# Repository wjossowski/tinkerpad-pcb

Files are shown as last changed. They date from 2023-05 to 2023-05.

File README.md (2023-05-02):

# tinkerpad

Programmable 4x4 Macropad with KMK

### Libraries:

- [GitHub - ebastler/marbastlib: A library collecting MX and Choc style footprints, as well as various other parts used to design custom keyboards](https://github.com/ebastler/marbastlib)

- [GitHub - foostan/kbd: for building keyboard libraries](https://github.com/foostan/kbd)

- [GitHub - ncarandini/KiCad-RP-Pico: A simple repository of files needed to add a 3D footprint of the Raspberry Pi Pico board to KiCad.](https://github.com/ncarandini/KiCad-RP-Pico)

### Todo (V3):

- [ ] RGB diode per key
- [ ] Serial interface plugins (UART, SPI)

### V2:

- [x] Chiral (flippable) board
- [x] Columnar stagger

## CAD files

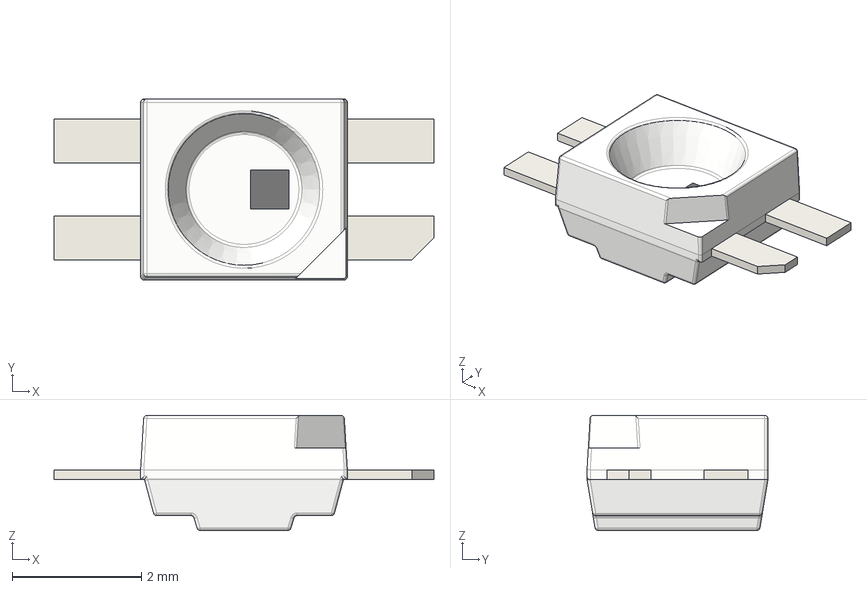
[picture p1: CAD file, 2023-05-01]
3dmodel/LED_SK6812MINI-E.step
5.88 x 2.80 x 1.78 mm

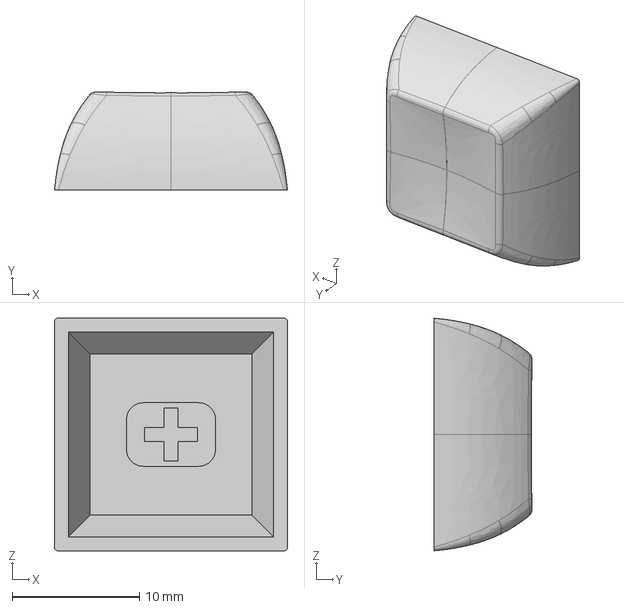
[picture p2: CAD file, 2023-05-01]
3dmodel/DSA_Keycap_CherryMX.step
18.3 x 7.69 x 18.3 mm

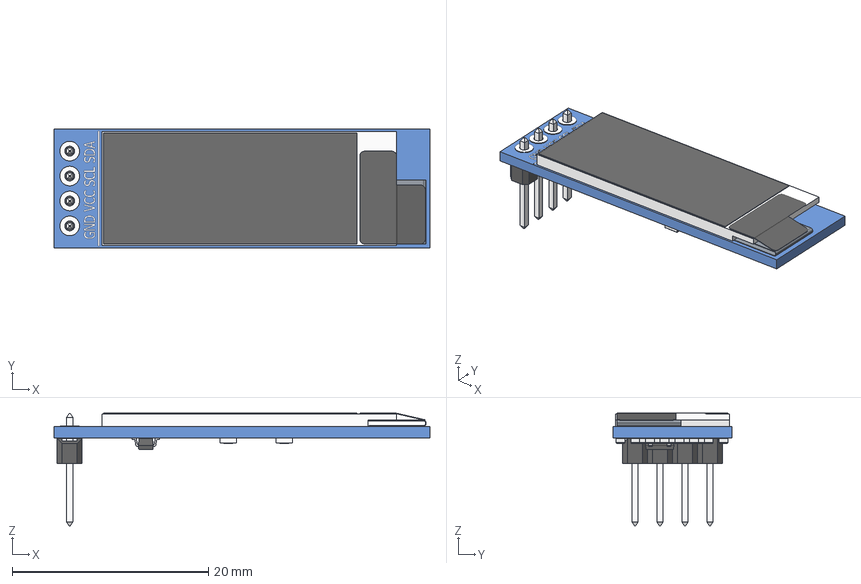
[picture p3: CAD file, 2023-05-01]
3dmodel/OLED_0.91_128x32.stp
38.3 x 12.1 x 11.5 mm
OLED_0.91_128x32
Pin Header 4 x 1 TH 2.54mm Pitch
RESC-0603 x 13
2SD0601A

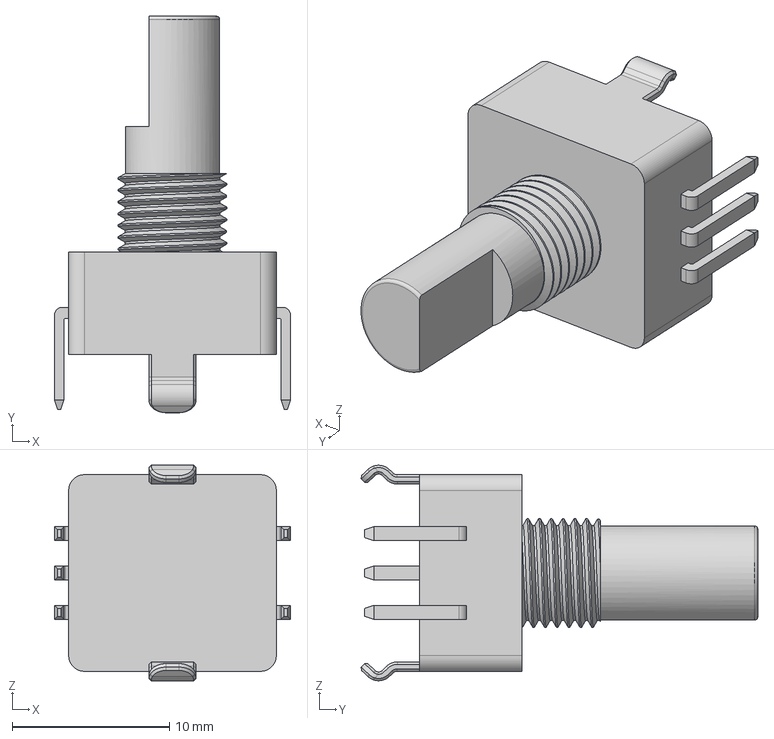
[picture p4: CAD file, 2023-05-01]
3dmodel/Rotary Encoder.step
15.0 x 25.2 x 13.7 mm

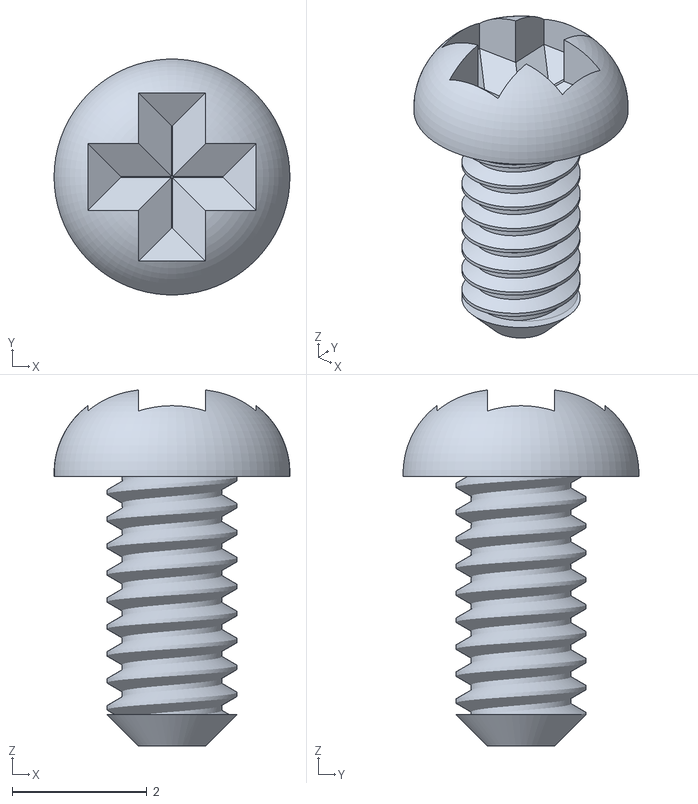
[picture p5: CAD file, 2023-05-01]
3dmodel/m2_screws/M2x4 v1.stl
3.50 x 3.50 x 5.28

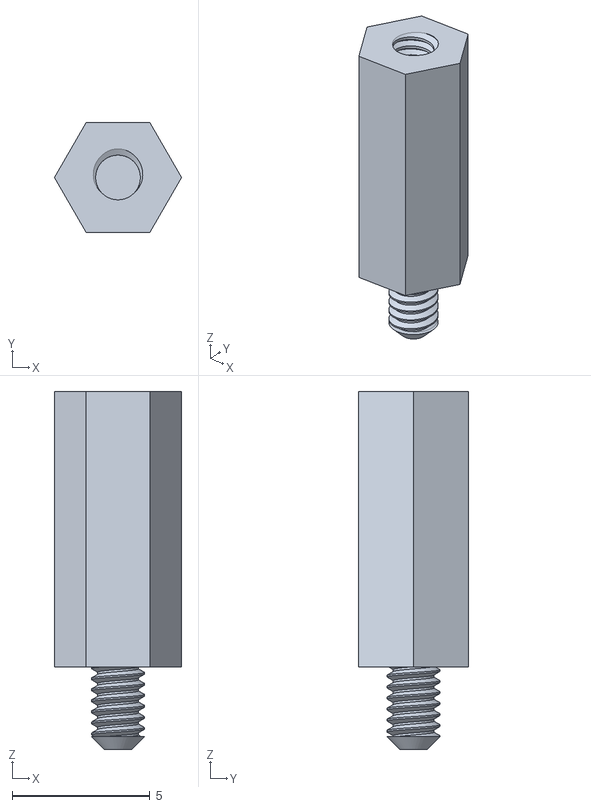
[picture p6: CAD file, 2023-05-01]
3dmodel/m2_screws/M2_10+3 v1.stl
4.62 x 4.00 x 13.0

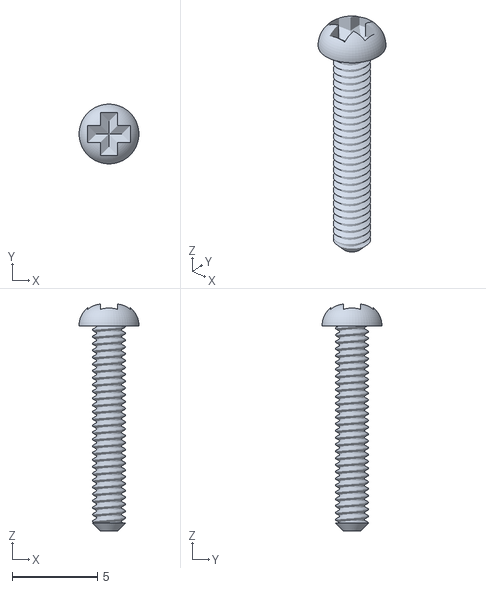
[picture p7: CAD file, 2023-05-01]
3dmodel/m2_screws/M2x12 v1.stl
3.50 x 3.50 x 13.3

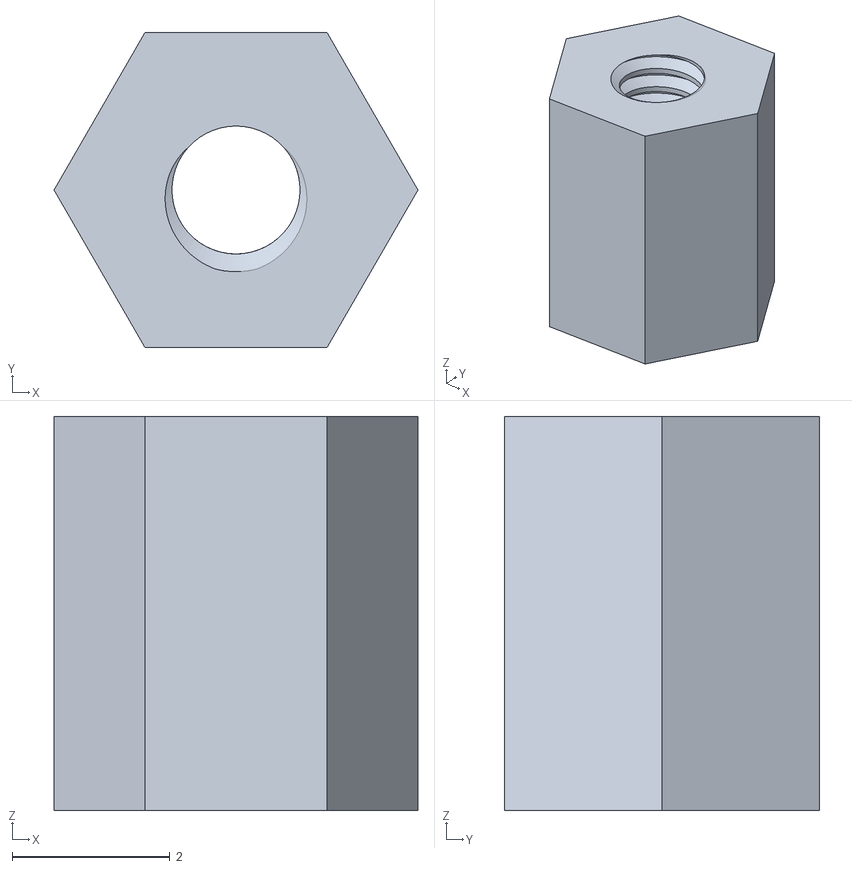
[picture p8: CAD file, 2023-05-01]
3dmodel/m2_screws/M2Sx5 v1.stl
4.62 x 4.00 x 5.00

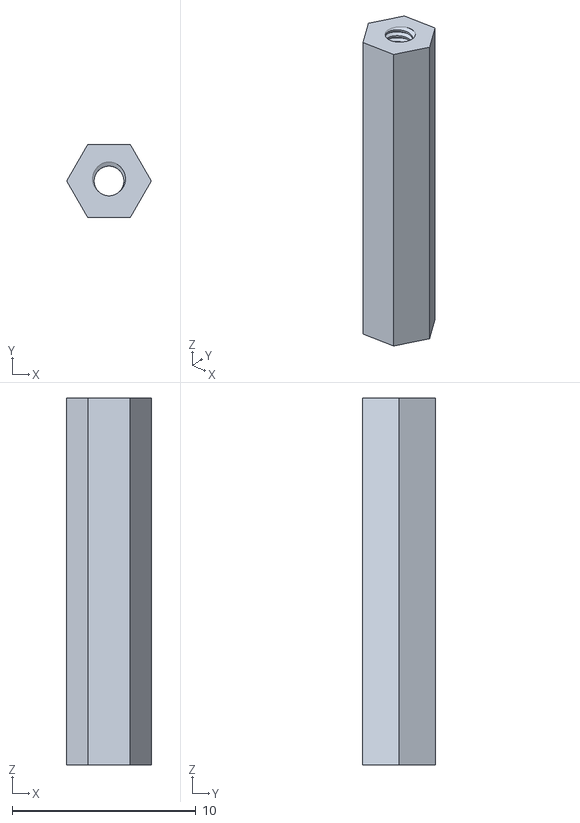
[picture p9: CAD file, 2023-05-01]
3dmodel/m2_screws/M2Sx20 v1.stl
4.62 x 4.00 x 20.0

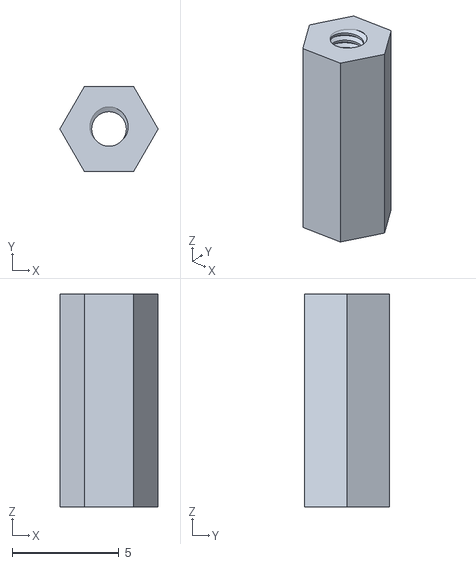
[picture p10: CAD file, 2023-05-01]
3dmodel/m2_screws/M2Sx10 v1.stl
4.62 x 4.00 x 10.0

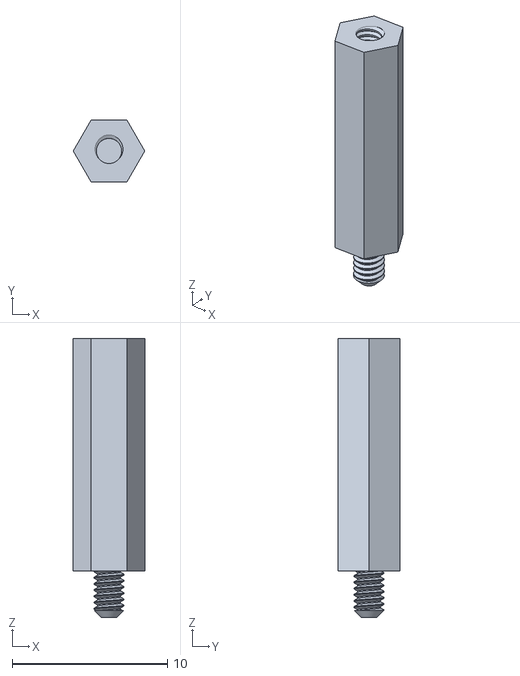
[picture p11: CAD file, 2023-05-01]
3dmodel/m2_screws/M2_15+3 v1.stl
4.62 x 4.00 x 18.0

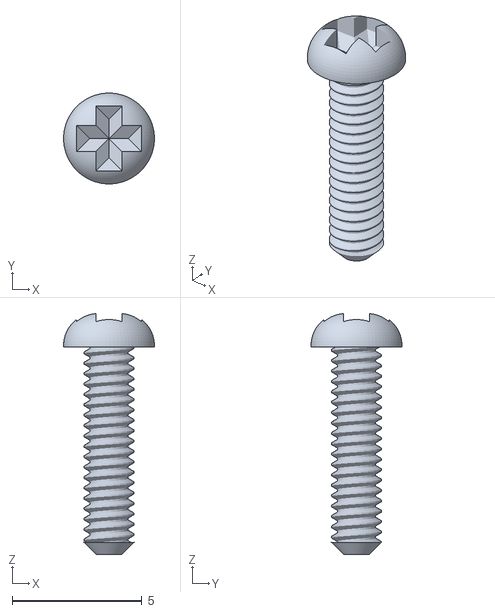
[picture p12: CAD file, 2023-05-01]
3dmodel/m2_screws/M2x8 v1.stl
3.50 x 3.50 x 9.28

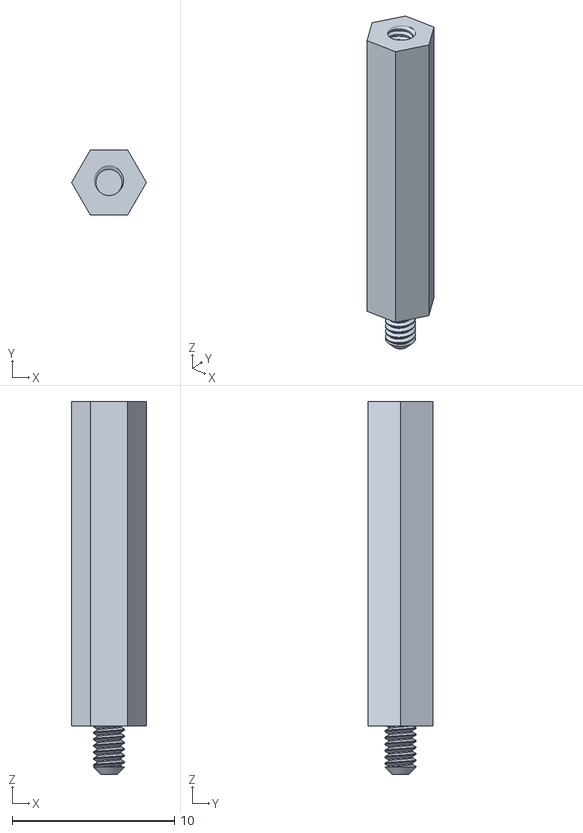
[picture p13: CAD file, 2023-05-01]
3dmodel/m2_screws/M2_20+3 v1.stl
4.62 x 4.00 x 23.0

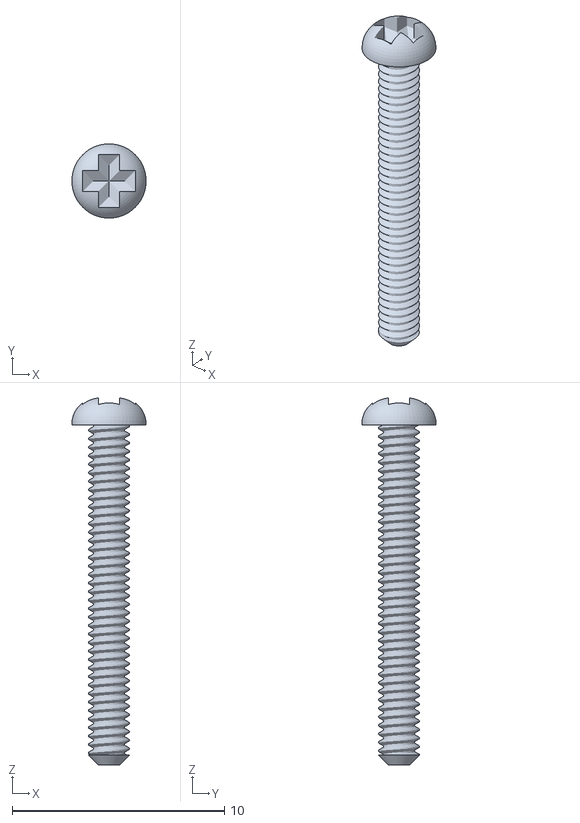
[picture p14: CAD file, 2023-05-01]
3dmodel/m2_screws/M2x16 v1.stl
3.50 x 3.50 x 17.3

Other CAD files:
3dmodel/m2_screws/m2_nut v1.stl
3dmodel/m2_screws/M2x6 v1.stl
3dmodel/m2_screws/M2x10 v1.stl
3dmodel/m2_screws/M2Sx15 v1.stl
3dmodel/m2_screws/M2_5+3 v1.stl

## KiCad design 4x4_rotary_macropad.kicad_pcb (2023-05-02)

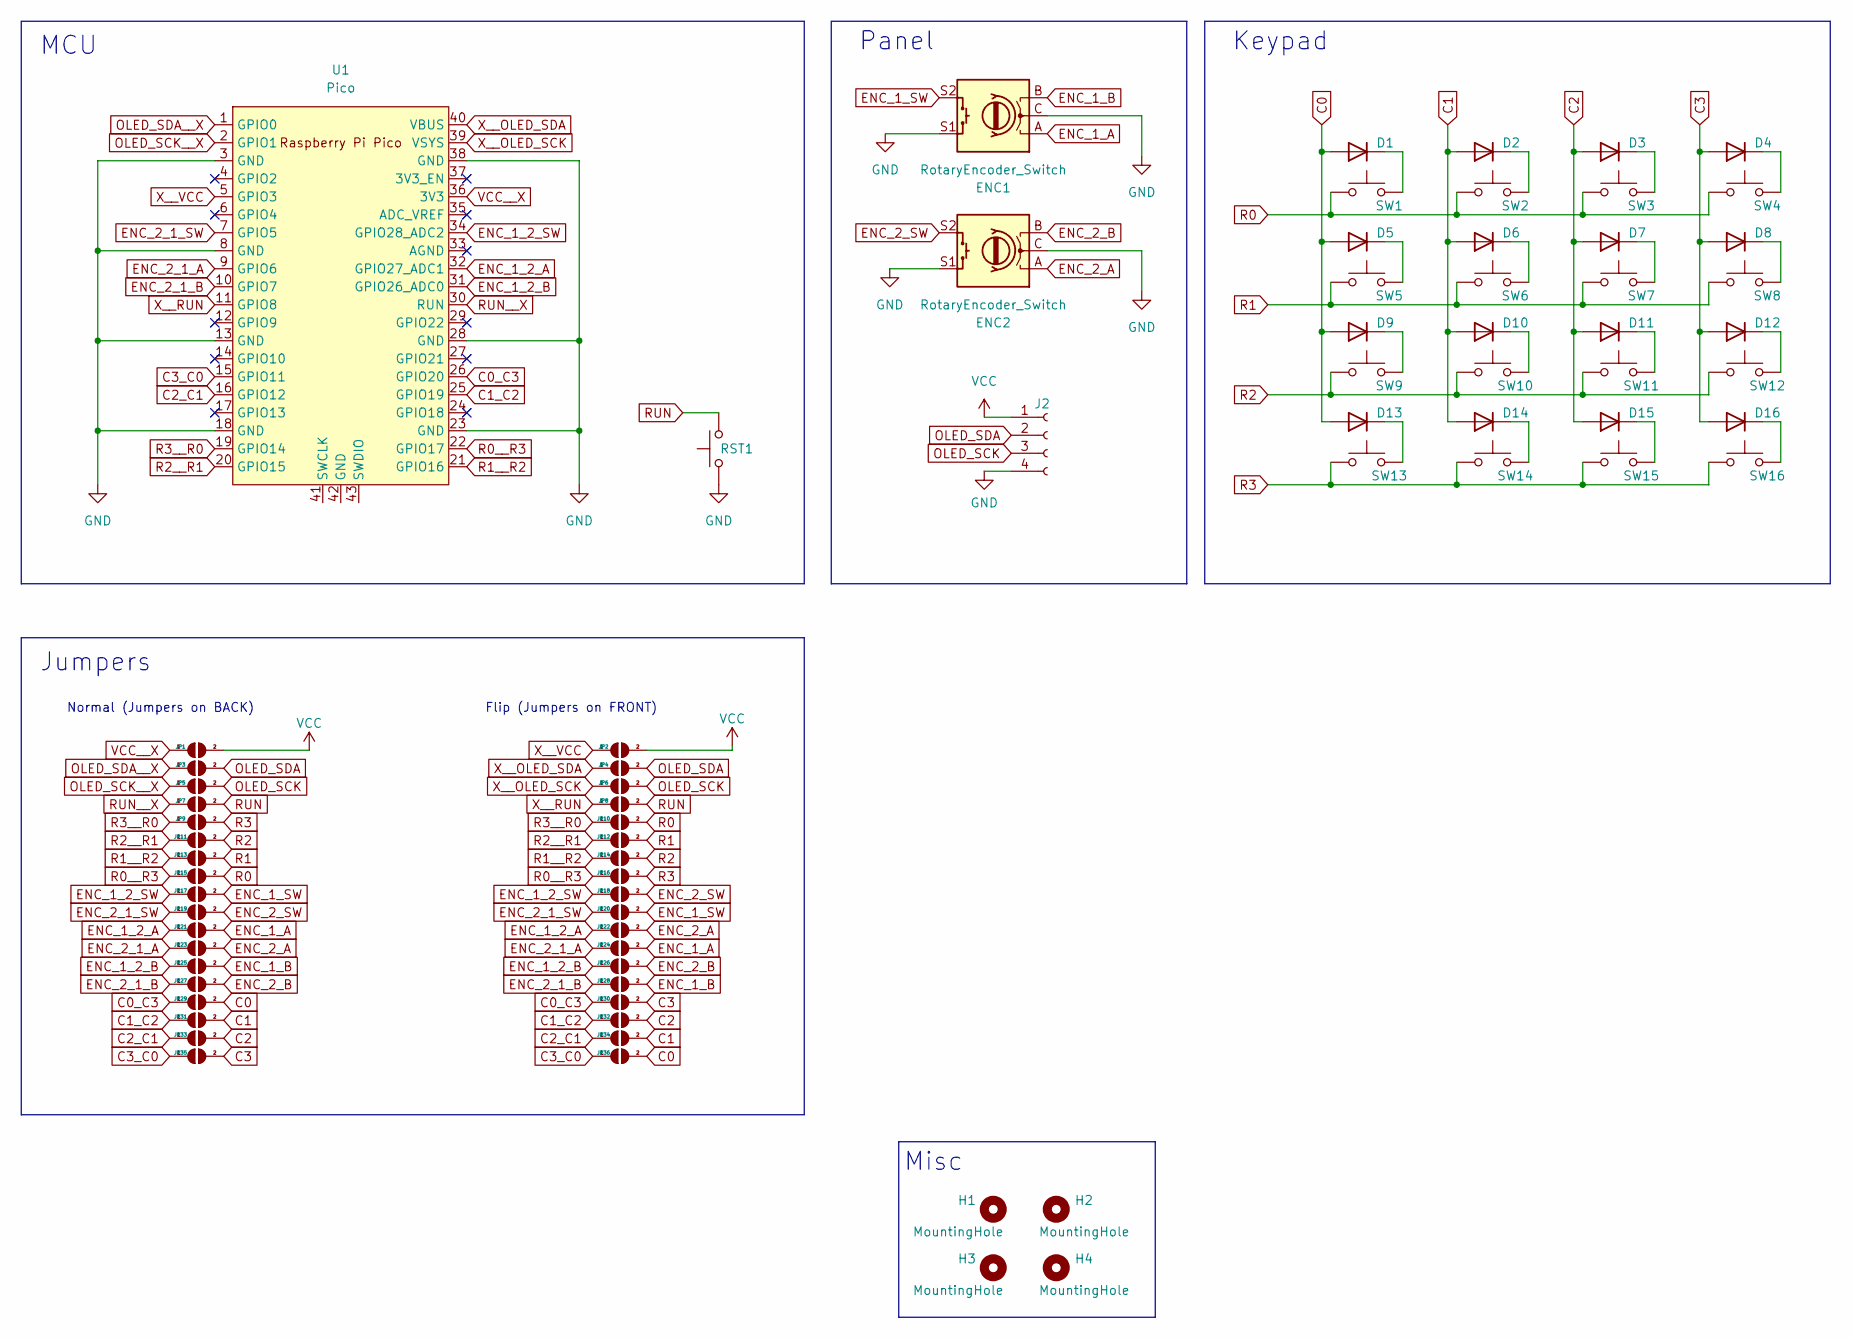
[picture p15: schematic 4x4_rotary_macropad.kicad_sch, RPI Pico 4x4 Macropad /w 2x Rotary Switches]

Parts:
D1, D2, D3, D4, D5, D6, D7, D8, D9, D10, D11, D12, D13, D14, D15, D16: e; D3_TH_SMD_v2
ENC1, ENC2: RotaryEncoder_Switch; RotaryEncoder_Alps_EC12E-Switch_Vertical_H20mm
H1, H2, H3, H4: MountingHole; MountingHole_2.2mm_M2
J2: Conn_01x04_Socket; Hirose_DF13-04P-1.25DSA_1x04_P1.25mm_Vertical
JP1, JP2, JP3, JP4, JP5, JP6, JP7, JP8, JP9, JP10, JP11, JP12, JP13, JP14, JP15, JP16, JP17, JP18, JP19, JP20, JP21, JP22, JP23, JP24, JP25, JP26, JP27, JP28, JP29, JP30, JP31, JP32, JP33, JP34, JP35, JP36: SolderJumper_2_Open; jumper
RST1: SW_Push; SW_SKHLLCA010
SW1, SW2, SW3, SW4, SW5, SW6, SW7, SW8, SW9, SW10, SW11, SW12, SW13, SW14, SW15, SW16: SW_Push; SW_Cherry_MX_PCB_1.00u
U1: Pico; RPi_Pico_SMD_TH

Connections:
C0: D1.2 (A), D5.2 (A), D9.2 (A), D13.2 (A), JP29.2 (B), JP36.2 (B)
C0_C3: JP29.1 (A), JP30.1 (A), U1.26 (GPIO20)
C1: D2.2 (A), D6.2 (A), D10.2 (A), D14.2 (A), JP31.2 (B), JP34.2 (B)
C1_C2: JP31.1 (A), JP32.1 (A), U1.25 (GPIO19)
C2: D3.2 (A), D7.2 (A), D11.2 (A), D15.2 (A), JP32.2 (B), JP33.2 (B)
C2_C1: JP33.1 (A), JP34.1 (A), U1.16 (GPIO12)
C3: D4.2 (A), D8.2 (A), D12.2 (A), D16.2 (A), JP30.2 (B), JP35.2 (B)
C3_C0: JP35.1 (A), JP36.1 (A), U1.15 (GPIO11)
ENC_1_2_A: JP21.1 (A), JP22.1 (A), U1.32 (GPIO27_ADC1)
ENC_1_2_B: JP25.1 (A), JP26.1 (A), U1.31 (GPIO26_ADC0)
ENC_1_2_SW: JP17.1 (A), JP18.1 (A), U1.34 (GPIO28_ADC2)
ENC_1_A: ENC1.A, JP21.2 (B), JP24.2 (B)
ENC_1_B: ENC1.B, JP25.2 (B), JP28.2 (B)
ENC_1_SW: ENC1.S2, JP17.2 (B), JP20.2 (B)
ENC_2_1_A: JP23.1 (A), JP24.1 (A), U1.9 (GPIO6)
ENC_2_1_B: JP27.1 (A), JP28.1 (A), U1.10 (GPIO7)
ENC_2_1_SW: JP19.1 (A), JP20.1 (A), U1.7 (GPIO5)
ENC_2_A: ENC2.A, JP22.2 (B), JP23.2 (B)
ENC_2_B: ENC2.B, JP26.2 (B), JP27.2 (B)
ENC_2_SW: ENC2.S2, JP18.2 (B), JP19.2 (B)
GND: ENC1.C, ENC1.S1, ENC2.C, ENC2.S1, J2.4, RST1.1, U1.3 (GND), U1.8 (GND), U1.13 (GND), U1.18 (GND), U1.23 (GND), U1.28 (GND), U1.38 (GND)
unnamed: D1.1 (K), SW1.2
unnamed: D2.1 (K), SW2.2
unnamed: D3.1 (K), SW3.2
unnamed: D4.1 (K), SW4.2
unnamed: D5.1 (K), SW5.2
unnamed: D6.1 (K), SW6.2
unnamed: D7.1 (K), SW7.2
unnamed: D8.1 (K), SW8.2
unnamed: D9.1 (K), SW9.2
unnamed: D10.1 (K), SW10.2
unnamed: D11.1 (K), SW11.2
unnamed: D12.1 (K), SW12.2
unnamed: D13.1 (K), SW13.2
unnamed: D14.1 (K), SW14.2
unnamed: D15.1 (K), SW15.2
unnamed: D16.1 (K), SW16.2
OLED_SCK: J2.3, JP5.2 (B), JP6.2 (B)
OLED_SCK__X: JP5.1 (A), U1.2 (GPIO1)
OLED_SDA: J2.2, JP3.2 (B), JP4.2 (B)
OLED_SDA__X: JP3.1 (A), U1.1 (GPIO0)
R0: JP10.2 (B), JP15.2 (B), SW1.1, SW2.1, SW3.1, SW4.1
R0__R3: JP15.1 (A), JP16.1 (A), U1.22 (GPIO17)
R1: JP12.2 (B), JP13.2 (B), SW5.1, SW6.1, SW7.1, SW8.1
R1__R2: JP13.1 (A), JP14.1 (A), U1.21 (GPIO16)
R2: JP11.2 (B), JP14.2 (B), SW9.1, SW10.1, SW11.1, SW12.1
R2__R1: JP11.1 (A), JP12.1 (A), U1.20 (GPIO15)
R3: JP9.2 (B), JP16.2 (B), SW13.1, SW14.1, SW15.1, SW16.1
R3__R0: JP9.1 (A), JP10.1 (A), U1.19 (GPIO14)
RUN: JP7.2 (B), JP8.2 (B), RST1.2
RUN__X: JP7.1 (A), U1.30 (RUN)
VCC: J2.1, JP1.2 (B), JP2.2 (B)
VCC__X: JP1.1 (A), U1.36 (3V3)
X__OLED_SCK: JP6.1 (A), U1.39 (VSYS)
X__OLED_SDA: JP4.1 (A), U1.40 (VBUS)
X__RUN: JP8.1 (A), U1.11 (GPIO8)
X__VCC: JP2.1 (A), U1.5 (GPIO3)

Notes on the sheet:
Keypad
Misc
Jumpers
Flip (Jumpers on FRONT)
Normal (Jumpers on BACK)
MCU
Panel

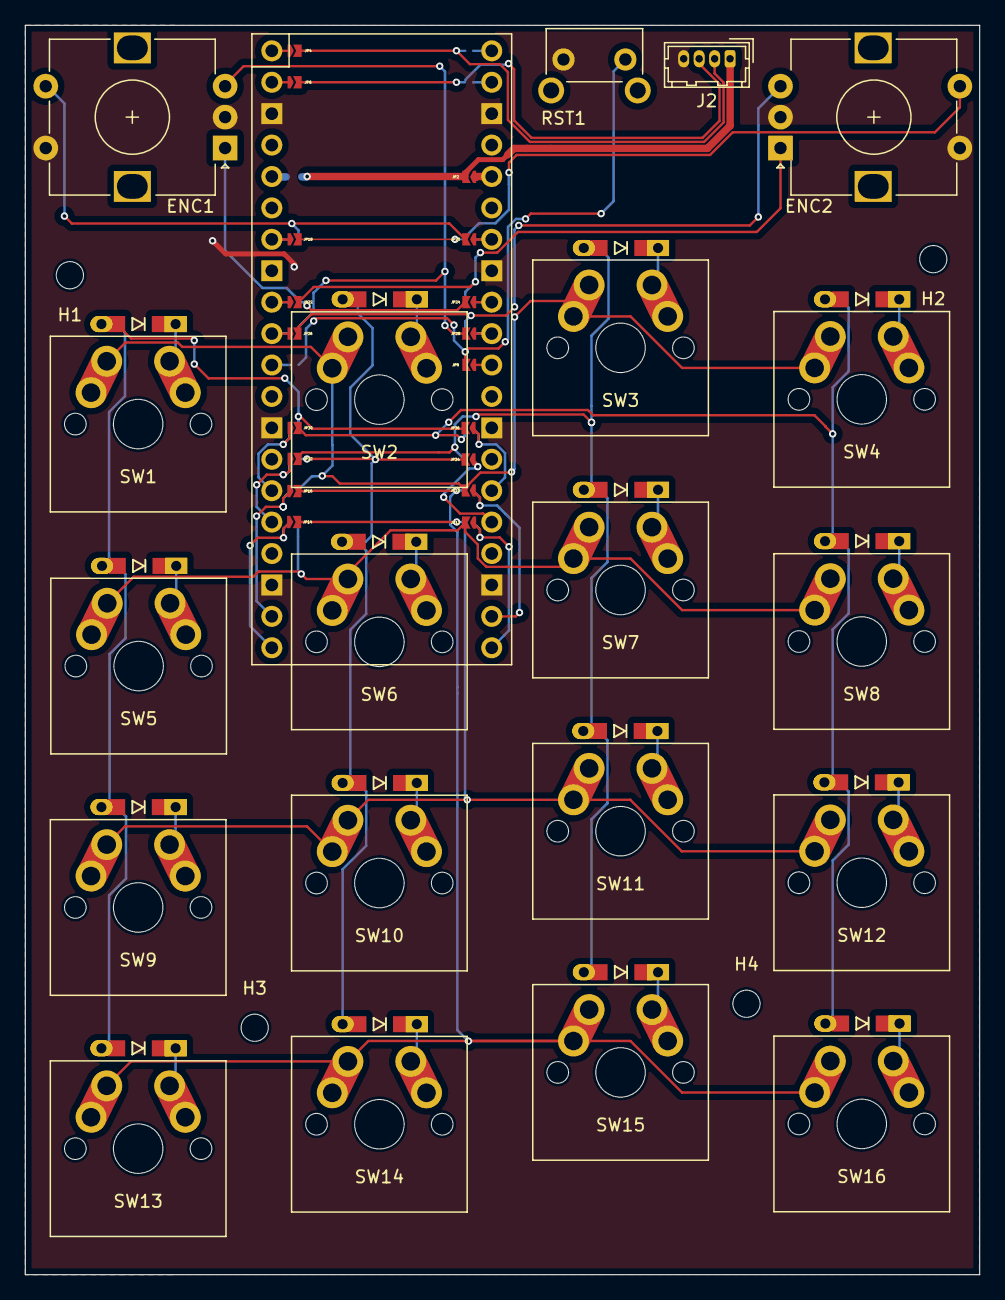
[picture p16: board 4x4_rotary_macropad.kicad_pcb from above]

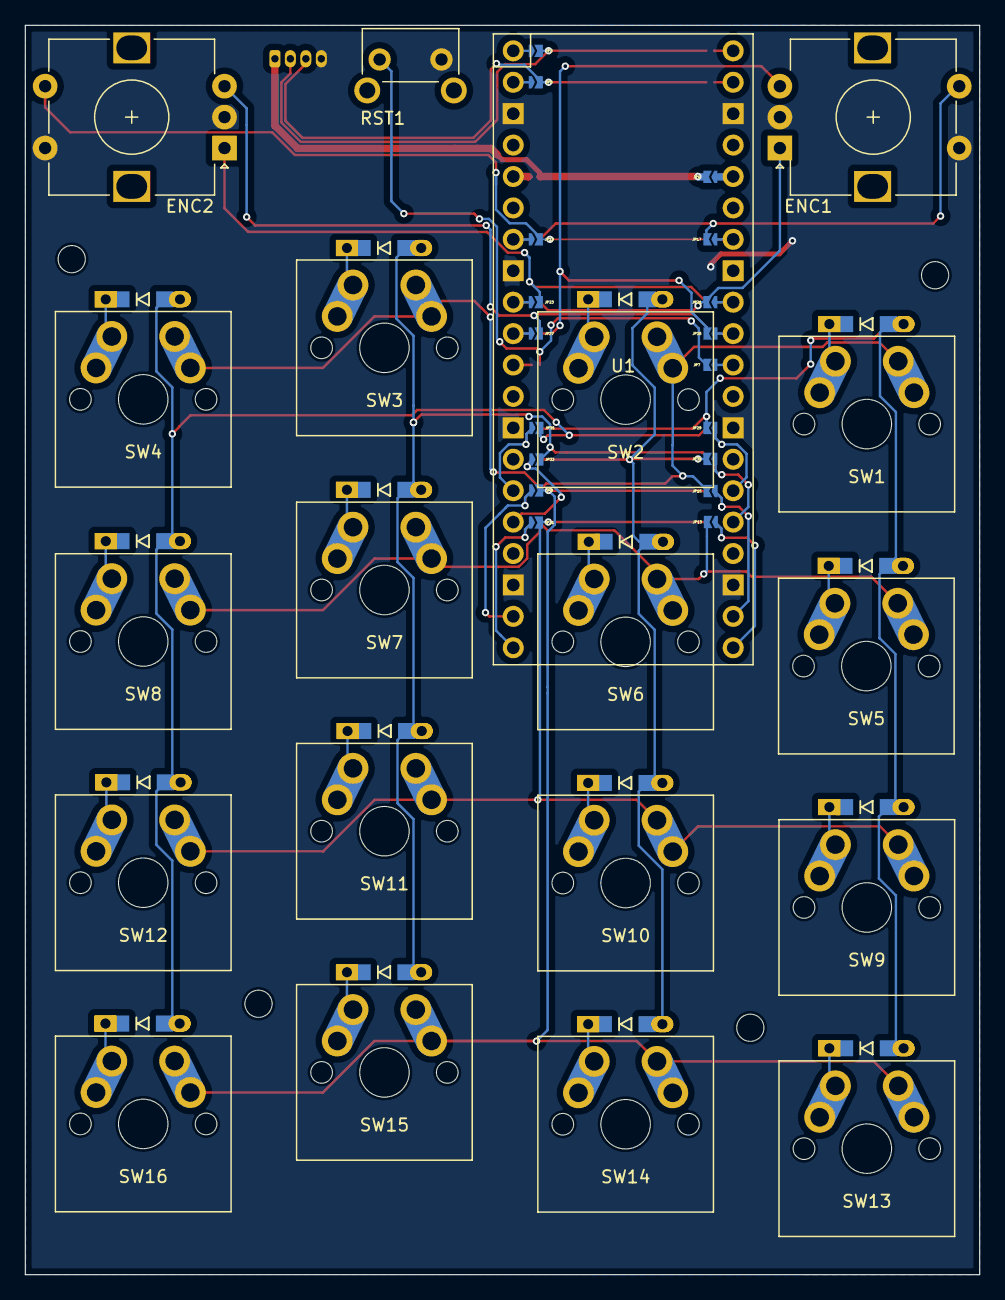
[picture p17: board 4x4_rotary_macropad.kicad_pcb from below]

Board: 2 copper layers, 77.1 x 101.0 mm, 77 parts (37 on the bottom side), 57 nets.

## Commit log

2023-05-01 Added KiCad .gitignore rules
2023-05-01 Added PCB Rev 0.2
    [4x4_rotary_macropad.kicad_pcb, 4x4_rotary_macropad.kicad_sch, DSA_Keycap_CherryMX.step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]
2023-05-01 Fixed JLCPCB constraints errors
    [4x4_rotary_macropad.kicad_pcb, 4x4_rotary_macropad.kicad_sch]
2023-05-01 Added missing libraries
    [4x4_rotary_macropad.kicad_pcb, 4x4_rotary_macropad.kicad_sch]
2023-05-02 Updated PCB properties
    [4x4_rotary_macropad.kicad_pcb]
